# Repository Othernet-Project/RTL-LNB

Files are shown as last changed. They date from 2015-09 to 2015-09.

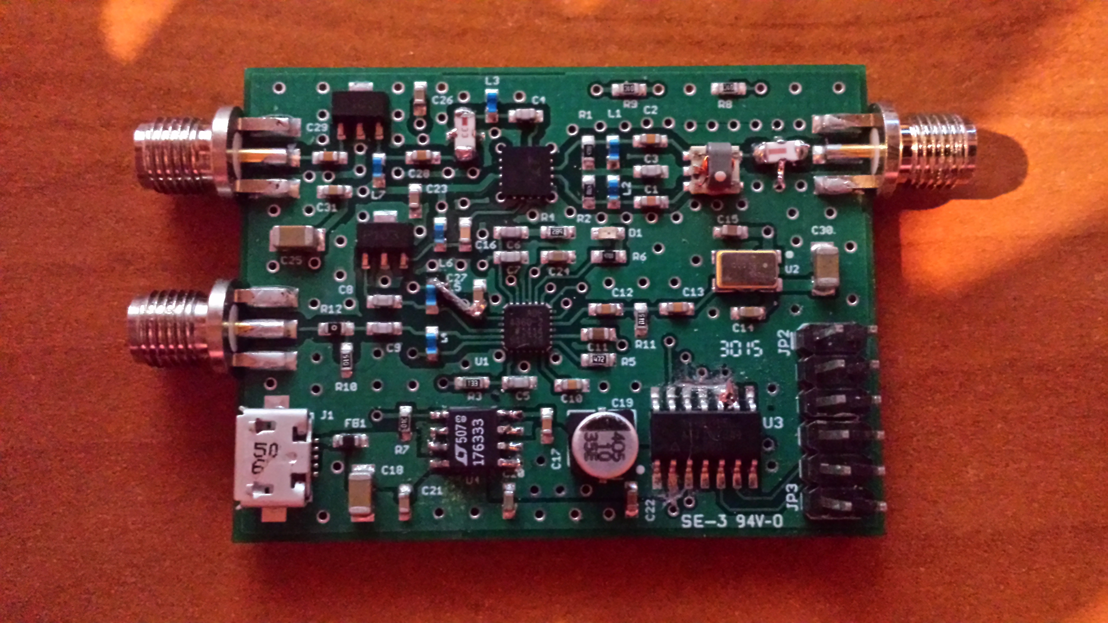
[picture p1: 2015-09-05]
LNB.jpg

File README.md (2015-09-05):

RTL-LNB
=======

Discussion and development of LNB that is used in conjunction with an rtl-sdr to downconvert L-band to a frequency more usable by the radio. 

Links
=====

http://goughlui.com/2013/11/10/rtl-sdr-a-tool-for-visualizing-broadcast-satellite-signals/
http://digitalbitrate.com/dtv.php?mux=11470&pid=33&live=65&lang=en

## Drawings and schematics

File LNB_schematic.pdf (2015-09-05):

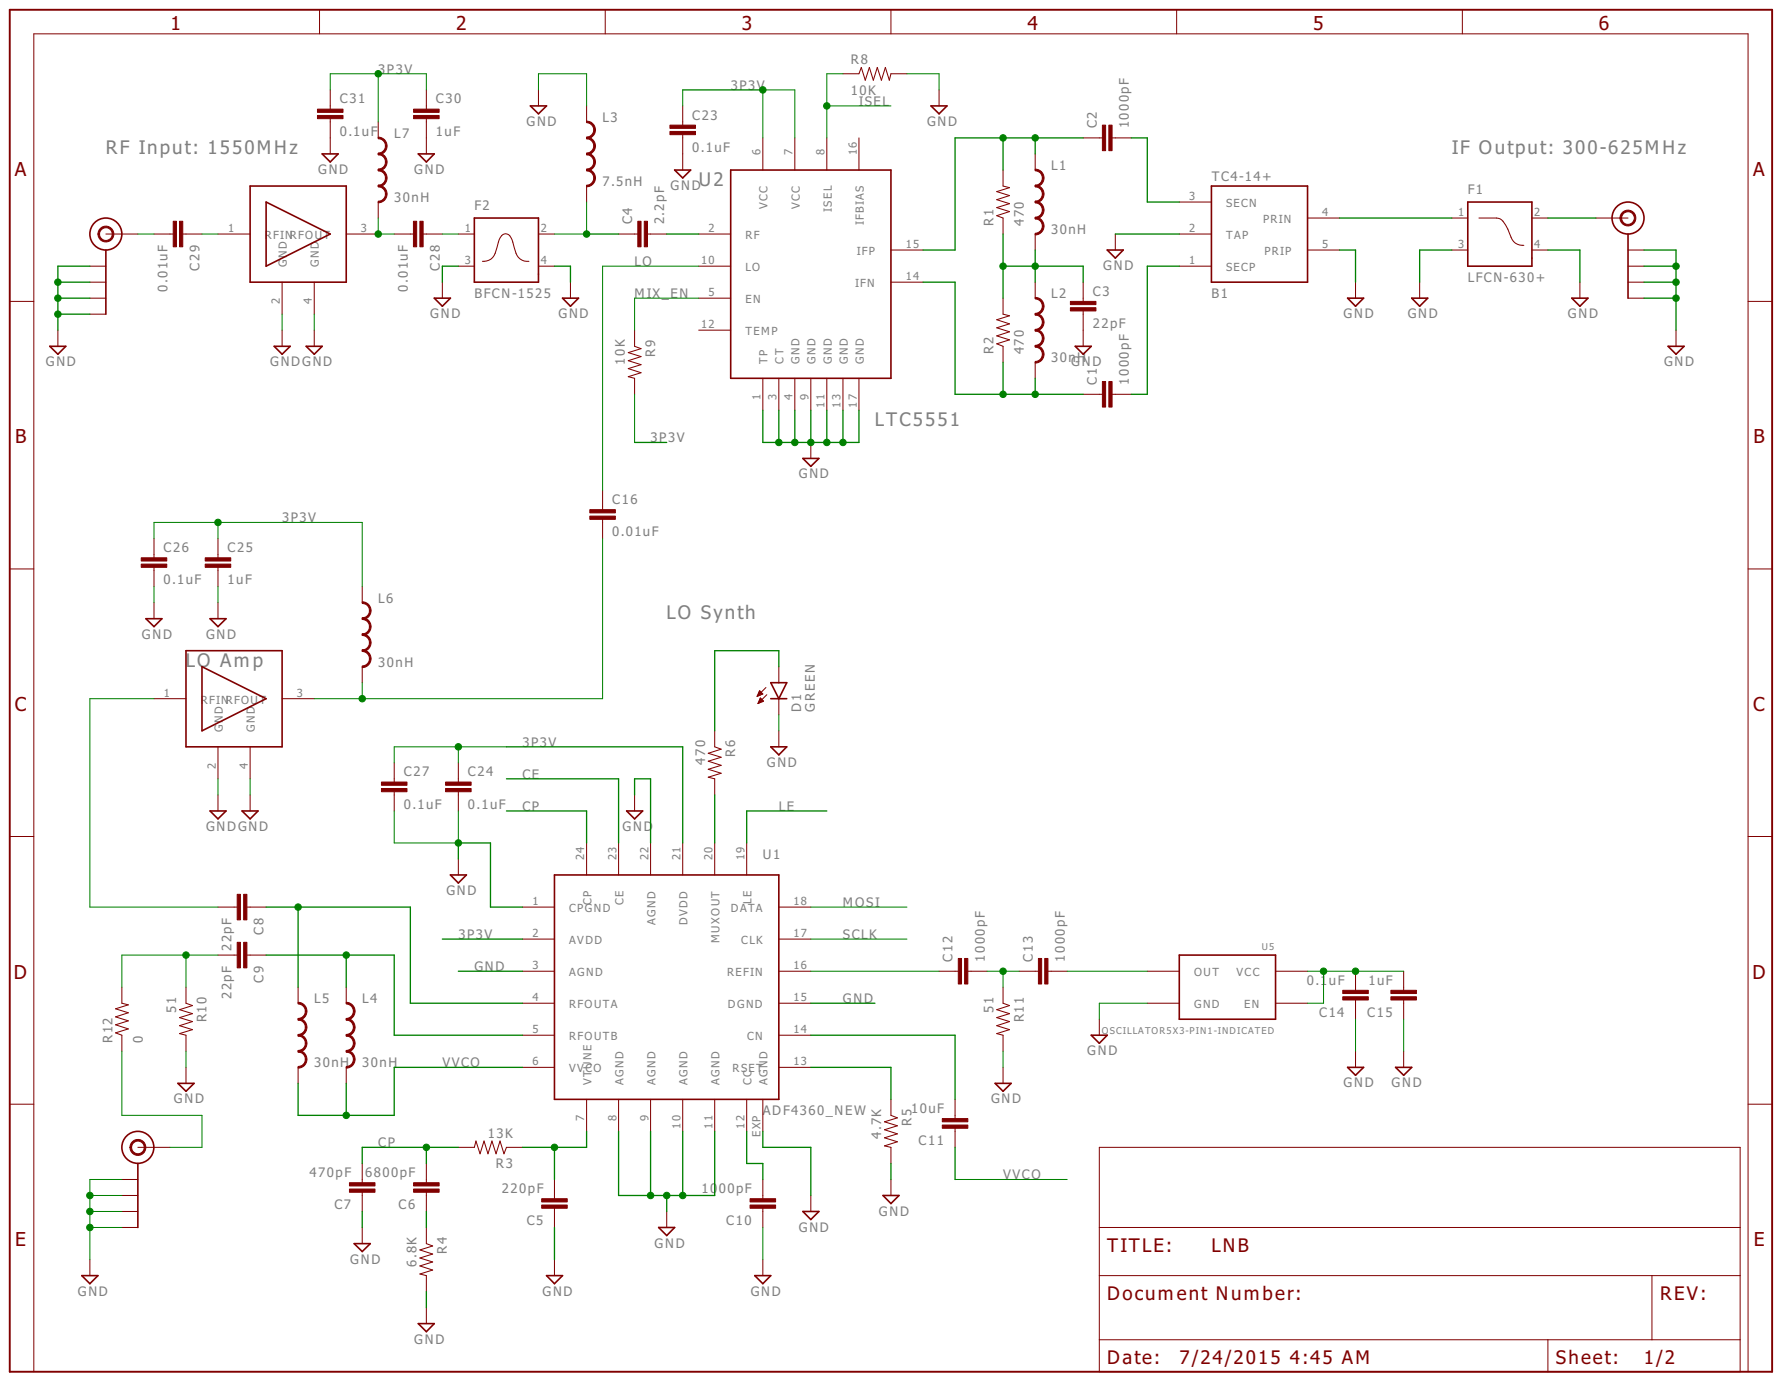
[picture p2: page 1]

REV: TITLE: Document Number: LNB

Date: 7/24/2015 4:45 AM | Sheet: 1/2

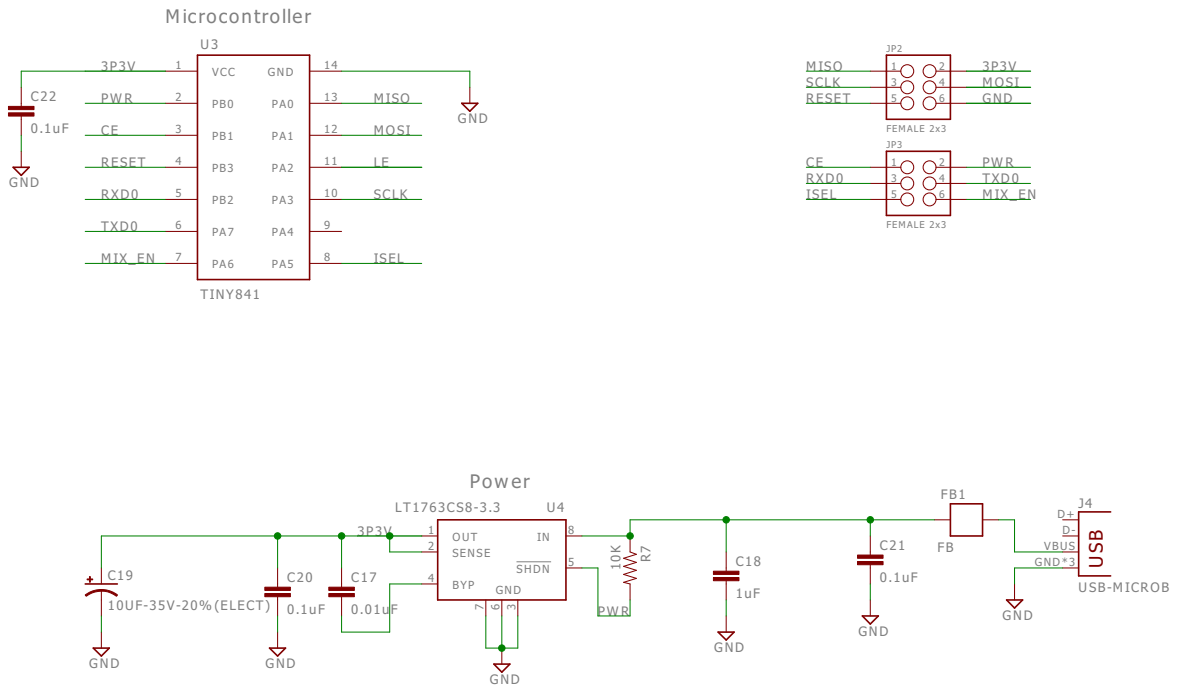
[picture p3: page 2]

REV: TITLE: Document Number: LNB

Date: 7/24/2015 4:45 AM | Sheet: 2/2

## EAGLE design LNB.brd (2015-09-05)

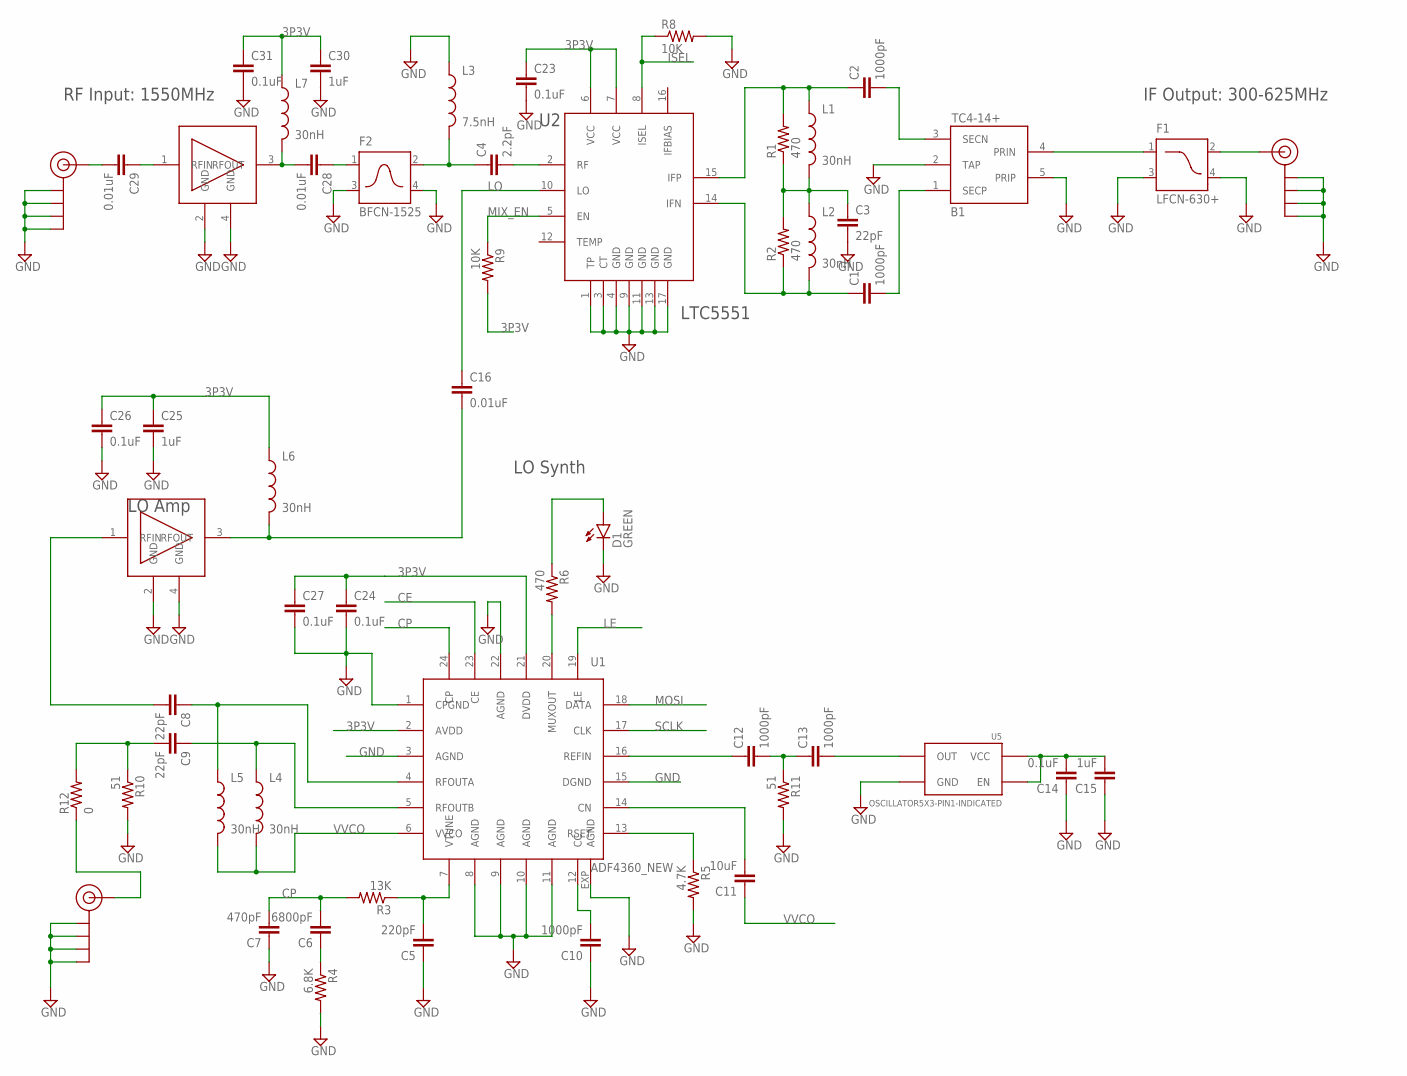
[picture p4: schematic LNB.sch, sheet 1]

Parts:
B1: TC4-14+; AT224-1
C1, C2, C10, C12, C13: 1000pF; 0603-CAP
C3, C8, C9: 22pF; 0603-CAP
C4: 2.2pF; 0603-CAP
C5: 220pF; 0603-CAP
C6: 6800pF; 0603-CAP
C7: 470pF; 0603-CAP
C11: 10uF; 0603-CAP
C14, C23, C24, C26, C27, C31: 0.1uF; 0603-CAP
C15: 1uF; 0603-CAP
C16, C28, C29: 0.01uF; 0603-CAP
C25, C30: 1uF; 1206
D1: GREEN; LED-0603
F1: LFCN-630+; FV1206_MC
F2: BFCN-1525; FV1206_MC
J2, J3: SMA_EDGE; SMA-EDGE
J$1: SMA_EDGE; SMA-EDGE
L1, L2, L4, L5, L6, L7: 30nH; 0603
L3: 7.5nH; 0603
R1, R2, R6: 470; 0603-RES
R3: 13K; 0603-RES
R4: 6.8K; 0603-RES
R5: 4.7K; 0603-RES
R8, R9: 10K; 0603-RES
R10, R11: 51; 0603-RES
R12: 0; 0603-RES
U1: ADF4360_NEW; LFCSP24
U2: LTC5551; QFN16-4X4
U5: OSCILLATOR5X3-PIN1-INDICATED; CRYSTAL-OSC-SMD-5X3
U6, U7: PGA-105+; SOT-89

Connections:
3P3V: C14.2, C15.2, C23.1, C24.1, C25.1, C26.1, C27.1, C30.1, C31.1, L6.1, L7.1, R9.2, U1.2 (AVDD), U1.21 (DVDD), U2.6 (VCC), U2.7 (VCC), U5.1 (EN), U5.4 (VCC); also elsewhere on the board
CE: U1.23 (CE); also elsewhere on the board
CP: C6.2, C7.2, R3.2, U1.24 (CP)
GND: B1.2 (TAP), B1.5 (PRIP), C3.2, C5.1, C7.1, C10.1, C14.1, C15.1, C23.2, C24.2, C25.2, C26.2, C27.2, C30.2, C31.2, D1.C, F1.3 (GND), F1.4 (GND), F2.3 (GND), F2.4 (GND), J2.GND@0 (GND), J2.GND@1 (GND), J2.GND@2 (GND), J2.GND@3 (GND), J3.GND@0 (GND), J3.GND@1 (GND), J3.GND@2 (GND), J3.GND@3 (GND), J$1.GND@0 (GND), J$1.GND@1 (GND), J$1.GND@2 (GND), J$1.GND@3 (GND), L3.1, R4.2, R5.2, R8.2, R10.2, R11.2, U1.1 (CPGND), U1.3 (AGND), U1.8 (AGND), U1.9 (AGND), U1.10 (AGND), U1.11 (AGND), U1.15 (DGND), U1.22 (AGND), U1.EXP (AGND), U2.1 (TP), U2.3 (CT), U2.4 (GND), U2.9 (GND), U2.11 (GND), U2.13 (GND), U2.17 (GND), U5.2 (GND), U6.2 (GND), U6.4 (GND), U7.2 (GND), U7.4 (GND); also elsewhere on the board
ISEL: R8.1, U2.8 (ISEL); also elsewhere on the board
LE: U1.19 (LE); also elsewhere on the board
LO: C16.1, U2.10 (LO)
LO_IN: C8.2, U7.1 (RFIN)
MIX_EN: R9.1, U2.5 (EN); also elsewhere on the board
MOSI: U1.18 (DATA); also elsewhere on the board
unnamed: C2.1, L1.1, R1.2, U2.15 (IFP)
unnamed: C1.1, L2.2, R2.1, U2.14 (IFN)
unnamed: C3.1, L1.2, L2.1, R1.1, R2.2
unnamed: B1.1 (SECP), C1.2
unnamed: B1.3 (SECN), C2.2
unnamed: B1.4 (PRIN), F1.1 (IN)
unnamed: F1.2 (OUT), J$1.SIG (SIGNAL)
unnamed: C29.2, J2.SIG (SIGNAL)
unnamed: C4.1, F2.2 (OUT), L3.2
unnamed: C4.2, U2.2 (RF)
unnamed: C5.2, R3.1, U1.7 (VTUNE)
unnamed: C11.2, U1.14 (CN)
unnamed: C6.1, R4.1
unnamed: C8.1, L5.1, U1.4 (RFOUTA)
unnamed: C9.1, L4.1, U1.5 (RFOUTB)
unnamed: C10.2, U1.12 (CC)
unnamed: D1.A, R6.1
unnamed: R5.1, U1.13 (RSET)
unnamed: R6.2, U1.20 (MUXOUT)
unnamed: C9.2, R10.1, R12.2
unnamed: C29.1, U6.1 (RFIN)
unnamed: C12.2, C13.1, R11.1
unnamed: C13.2, U5.3 (OUT)
unnamed: C12.1, U1.16 (REFIN)
unnamed: C16.2, L6.2, U7.3 (RFOUT)
unnamed: J3.SIG (SIGNAL), R12.1
unnamed: C28.2, L7.2, U6.3 (RFOUT)
unnamed: C28.1, F2.1 (IN)
SCLK: U1.17 (CLK); also elsewhere on the board
VVCO: C11.1, L4.2, L5.2, U1.6 (VVCO)

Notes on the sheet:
RF Input: 1550MHz
IF Output: 300-625MHz
LO Synth
LO Amp
LTC5551

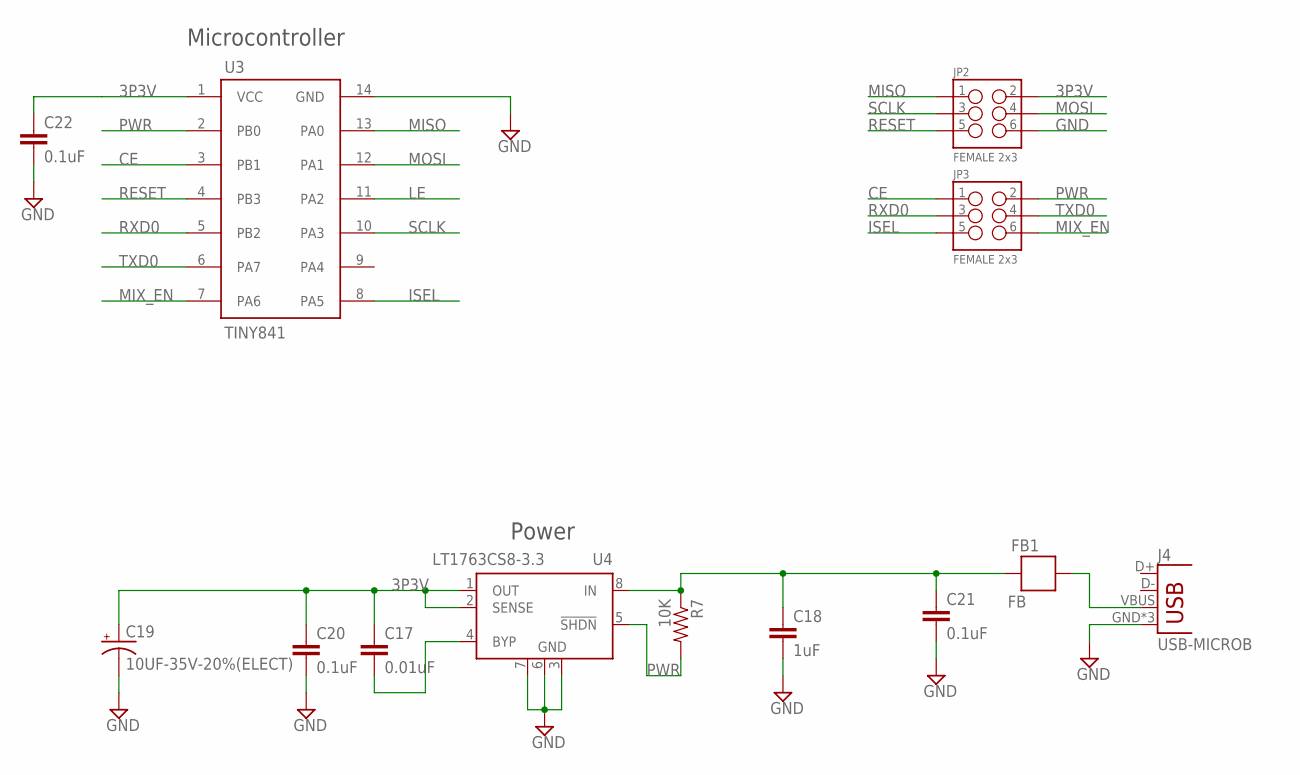
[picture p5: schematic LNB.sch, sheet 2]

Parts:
C17: 0.01uF; 0603-CAP
C18: 1uF; 1206
C19: 10UF-35V-20%(ELECT); PANASONIC_C
C20, C21, C22: 0.1uF; 0603-CAP
FB1: FB; 0603
J4: USB-MICROB
JP2, JP3: FEMALE 2x3; 2X3
R7: 10K; 0603-RES
U3: TINY841; SOIC14
U4: LT1763CS8-3.3; SOIC8

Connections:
3P3V: C17.1, C19.+, C20.1, C22.1, JP2.2, U3.1 (VCC), U4.1 (OUT), U4.2 (SENSE); also elsewhere on the board
CE: JP3.1, U3.3 (PB1); also elsewhere on the board
GND: C18.2, C19.-, C20.2, C21.2, C22.2, J4.GND, J4.MT1 (GND), J4.MT2 (GND), JP2.6, U3.14 (GND), U4.3 (GND), U4.6 (GND), U4.7 (GND); also elsewhere on the board
ISEL: JP3.5, U3.8 (PA5); also elsewhere on the board
LE: U3.11 (PA2); also elsewhere on the board
MISO: JP2.1, U3.13 (PA0)
MIX_EN: JP3.6, U3.7 (PA6); also elsewhere on the board
MOSI: JP2.4, U3.12 (PA1); also elsewhere on the board
unnamed: FB1.1, J4.VBUS
unnamed: C18.1, C21.1, FB1.2, R7.1, U4.8 (IN)
unnamed: C17.2, U4.4 (BYP)
PWR: JP3.2, R7.2, U3.2 (PB0), U4.5 (!SHDN)
RESET: JP2.5, U3.4 (PB3)
RXD0: JP3.3, U3.5 (PB2)
SCLK: JP2.3, U3.10 (PA3); also elsewhere on the board
TXD0: JP3.4, U3.6 (PA7)

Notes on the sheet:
Microcontroller
Power

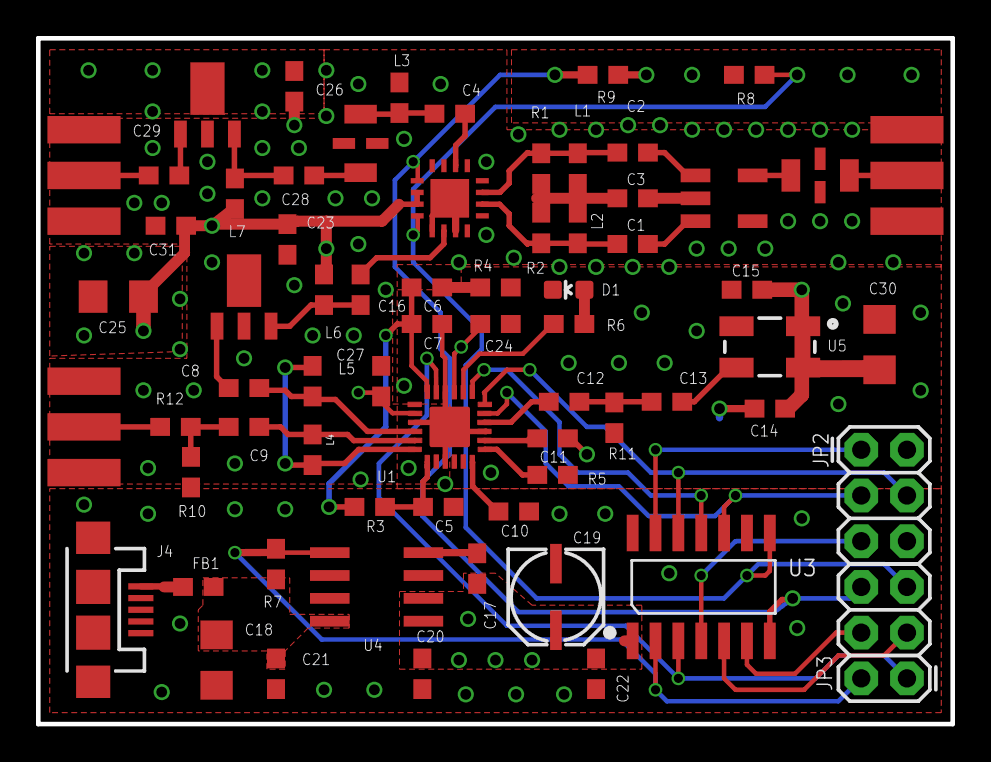
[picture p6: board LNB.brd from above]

Board: 4 copper layers, 50.8 x 38.1 mm, 68 parts (0 on the bottom side), 48 nets.

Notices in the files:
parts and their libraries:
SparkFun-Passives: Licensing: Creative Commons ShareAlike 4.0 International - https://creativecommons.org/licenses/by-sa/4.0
